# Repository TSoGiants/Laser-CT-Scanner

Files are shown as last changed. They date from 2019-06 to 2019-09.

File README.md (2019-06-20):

# About The Shoulders of Giants
In 1676, Isaac Newton, one of the most influential mathematicians and scientists of all time, famously wrote:

> "If I have seen further, it is by standing on the shoulders of giants."

The Shoulders of Giants, Inc. (TSoG) is a nonprofit (501(c)(3)) organization founded in 2013 on a vision that world-class science education should be available to all students of all ages. Since 2015, The Shoulders of Giants has offered an immersive, ongoing mentorship program for dedicated students who would like the opportunity to study more closely under the guidance of Dr. Steven J. Foland. This program is designed to provide middle and high school students with a broad foundation of knowledge and skills across science and engineering disciplines, experience working and communicating in a professional environment, and helps them develop the study habits necessary to achieve success at the university level and beyond.

In 2019, this world-class program became available to students everywhere with the launch of TSoG.tv. This online platform, created in collaboration between The Shoulders of Giants, Inc. and its sister-company Floating Point Laboratories, LLC, provides at-home exercises, live-streaming, and project support to students anywhere in the world.

## About Work in Progress
Work in Progress (WiP) is the main Kepler-level (high school) series on TSoG.tv, focused on multi-disciplinary engineering and applied science.

As the late, great astrophysicist and science advocate Carl Sagan once said: "If you wish to make an apple pie from scratch, you must first invent the universe." With that great quote in mind, this is a series where we bake the whole pie. In each season of Work in Progress we propose a practical project, lay out specifications, then discuss all of the relevant background knowledge necessary to take that project to completion.

Episodes of WiP air live on www.twitch.tv/tsogtv and are archived at www.youtube.com/tsogtv. This project is based on the work completed in episodes that aired on Monday evenings in Summer 2019.

# Laser CT Scanner
## History and Motivation

## Current State
As the name of the series implies, this redesign is currently a work in progress. This section of the README will be kept up-to-date with the current state of the project as the season progresses.

### Design Inputs
* Should function as closely in general operation to an actual CT scanner as possible.
* At least 1 motorized D.O.F.
* Must be able to independently capture a full 2D slice of an opaque object.
* Must be able to transmit raw data to a computer.
* Must be able to adjust height / z-axis of scan on object (manually or otherwise).

### Stretch Goals
* Able to image semi-opaque materials.
* Scanner rotates around subject rather than rotating the subject.
* Motorized z-axis.

### How to Collaborate
For any active TSoG.tv students who would like to contribute to this project, please create a GitHub account and contact Dr. Foland via Discord. He will need your GitHub username to grant you permission to modify this repository.

This project includes mechanical CAD that we will be completing in Alibre Design. You can download a 30 day trial of this software [here](https://www.alibre.com/get-a-trial-of-alibre-design-expert/). Students active on this project should discuss longer-term licensing options with Dr. Foland.

This project also includes electricad CAD that we will be completing in KiCAD. You can download this open source software [here](http://www.kicad-pcb.org/).

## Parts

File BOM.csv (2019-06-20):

Description | Part Number | Distributor | Link | Unit Cost | Quantity | Total Cost | Notes | Potential Alternative
Line Laser Diode - 5mW 650nm Red | 1057 | Adafruit | https://www.adafruit.com/product/1057 | $8.95 | 1 | $8.95

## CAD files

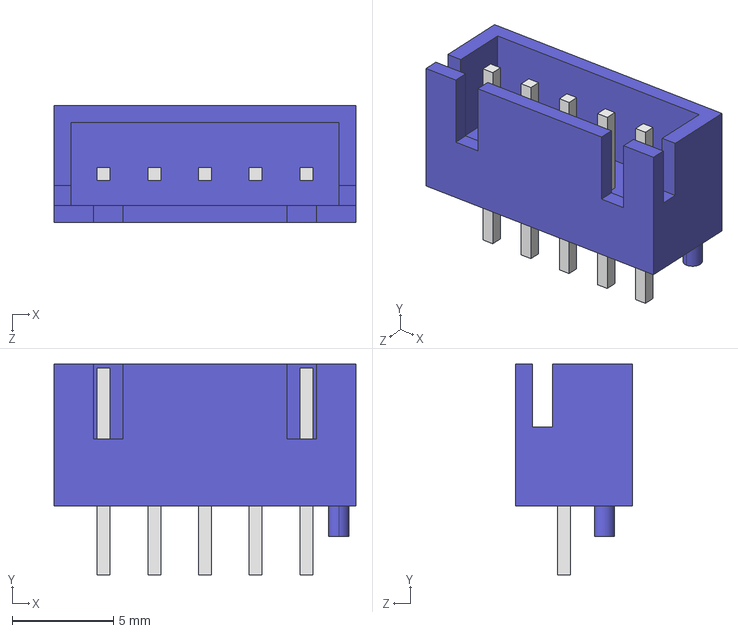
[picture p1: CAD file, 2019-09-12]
Electrical/_lib/3D/B5B-XH-AM.IGS
14.9 x 10.4 x 5.75 mm

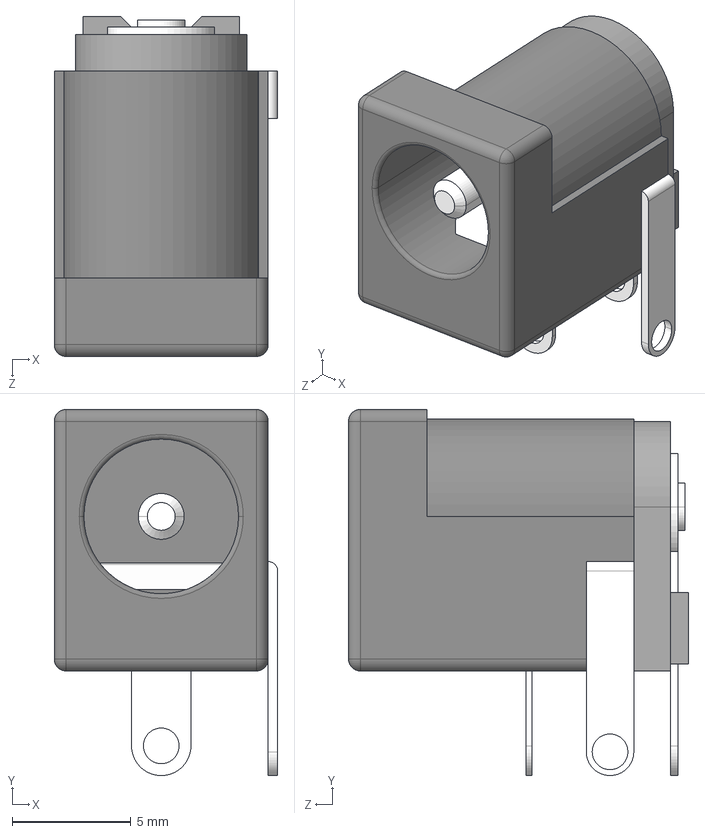
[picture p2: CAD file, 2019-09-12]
Electrical/_lib/3D/DC-005--3DModel-STEP-56544.STEP
9.40 x 15.4 x 14.3 mm

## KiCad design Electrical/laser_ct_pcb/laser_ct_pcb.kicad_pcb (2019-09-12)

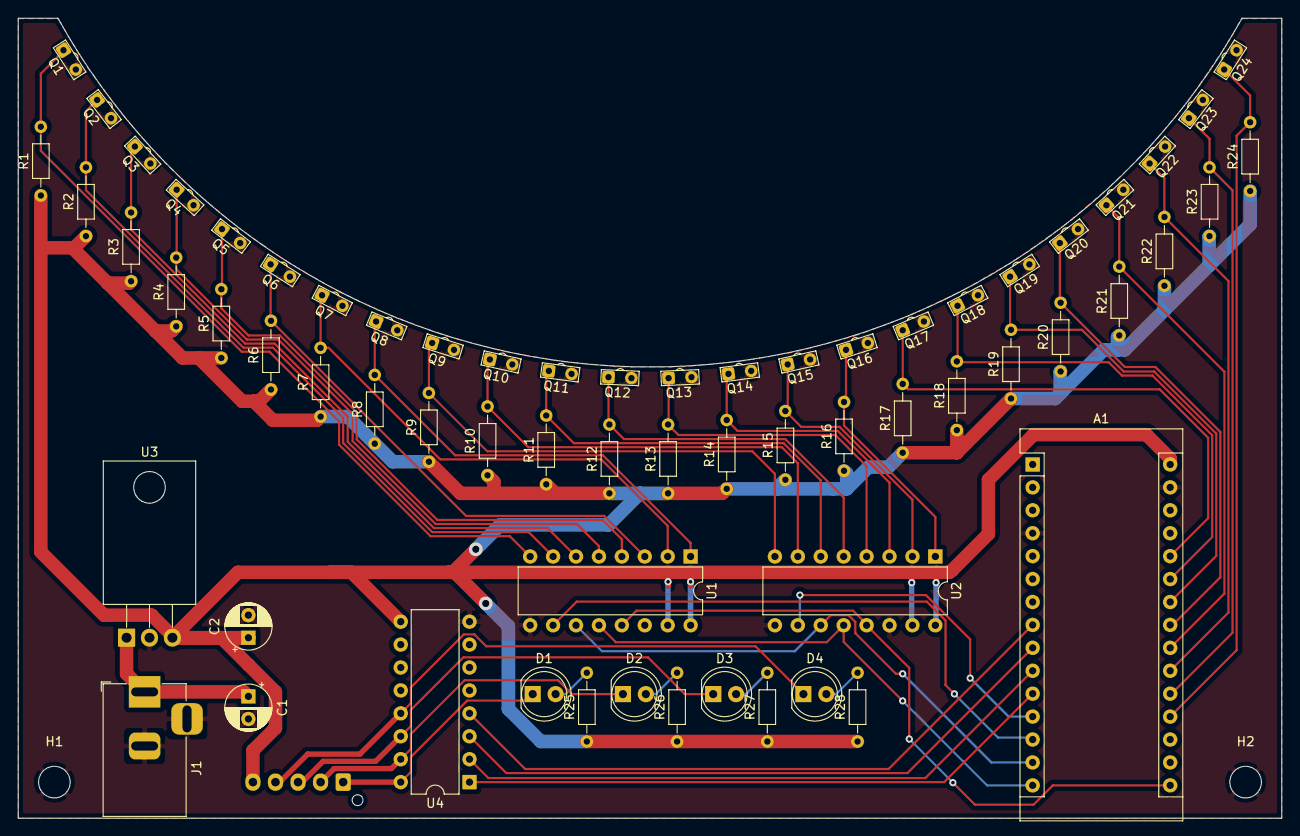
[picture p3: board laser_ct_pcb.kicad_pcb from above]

Board: 2 copper layers, 140.0 x 88.6 mm, 67 parts (1 on the bottom side), 44 nets.

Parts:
A1: Arduino_Nano_v3.x; Arduino_Nano
C1: 0.1uF; CP_Radial_D5.0mm_P2.50mm
C2: 10uF; CP_Radial_D5.0mm_P2.50mm
D1, D2, D3, D4: LED; LED_D5.0mm
H1, H2: MountingHole_Pad; MountingHole_3.5mm
J1: Barrel_Jack_Switch; BarrelJack_Horizontal
M1: 28BYJ-48; JST_XH_B5B-XH-AM_1x05_P2.50mm_Vertical
Q1, Q2, Q3, Q4, Q5, Q6, Q7, Q8, Q9, Q10, Q11, Q12, Q13, Q14, Q15, Q16, Q17, Q18, Q19, Q20, Q21, Q22, Q23, Q24: Q_Photo_NPN; LTR_301
R1, R2, R3, R4, R5, R6, R7, R8, R9, R10, R11, R12, R13, R14, R15, R16, R17, R18, R19, R20, R21, R22, R23, R24: 1 kOhm; R_Axial_DIN0204_L3.6mm_D1.6mm_P7.62mm_Horizontal
R25, R26, R27, R28: R_US; R_Axial_DIN0204_L3.6mm_D1.6mm_P7.62mm_Horizontal
U1, U2: MCP3008; DIP-16_W7.62mm
U3: MIC29310-5.0WT; TO-220-3_Horizontal_TabDown
U4: ULN2003A; DIP-16_W7.62mm

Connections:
+5V: A1.30, C2.1, M1.5, R1.1, R2.1, R3.1, R4.1, R5.1, R6.1, R7.1, R8.1, R9.1, R10.1, R11.1, R12.1, R13.1, R14.1, R15.1, R16.1, R17.1, R18.1, R19.1, R20.1, R21.1, R22.1, R23.1, R24.1, R25.1, R26.1, R27.1, R28.1, U1.15, U1.16, U2.15, U2.16, U3.3, U4.9
+VDC: C1.1, J1.1, U3.1
/A: D1.1, M1.1, U4.16
/B: D2.1, M1.2, U4.15
/C: D3.1, M1.3, U4.14
/D: D4.1, M1.4, U4.13
/M1: A1.11, U4.1
/M2: A1.10, U4.2
/M3: A1.9, U4.3
/M4: A1.8, U4.4
/PT2: Q2.1, R2.2, U1.7
/PT3: Q3.1, R3.2, U1.6
/PT4: Q4.1, R4.2, U1.5
/PT5: Q5.1, R5.2, U1.4
/PT6: Q6.1, R6.2, U1.3
/PT7: Q7.1, R7.2, U1.2
/PT8: Q8.1, R8.2, U1.1
/PT10: Q10.1, R10.2, U2.7
/PT11: Q11.1, R11.2, U2.6
/PT12: Q12.1, R12.2, U2.5
/PT13: Q13.1, R13.2, U2.4
/PT14: Q14.1, R14.2, U2.3
/PT15: Q15.1, R15.2, U2.2
/PT16: Q16.1, R16.2, U2.1
/Phototransistors/PT1: Q1.1, R1.2, U1.8
/Phototransistors/PT9: Q9.1, R9.2, U2.8
/Phototransistors/PT17: A1.26, Q17.1, R17.2
/Phototransistors/PT18: A1.25, Q18.1, R18.2
/Phototransistors/PT19: A1.24, Q19.1, R19.2
/Phototransistors/PT20: A1.23, Q20.1, R20.2
/Phototransistors/PT21: A1.22, Q21.1, R21.2
/Phototransistors/PT22: A1.21, Q22.1, R22.2
/Phototransistors/PT23: A1.20, Q23.1, R23.2
/Phototransistors/PT24: A1.19, Q24.1, R24.2
GND: A1.4, A1.29, C1.2, C2.2, H1.1, H2.1, J1.2, J1.3, Q1.2, Q2.2, Q3.2, Q4.2, Q5.2, Q6.2, Q7.2, Q8.2, Q9.2, Q10.2, Q11.2, Q12.2, Q13.2, Q14.2, Q15.2, Q16.2, Q17.2, Q18.2, Q19.2, Q20.2, Q21.2, Q22.2, Q23.2, Q24.2, U1.9, U1.14, U2.9, U2.14, U3.2, U4.8
unnamed: A1.12, U2.10
unnamed: A1.13, U1.10
unnamed: A1.14, U1.11, U2.11
unnamed: A1.15, U1.12, U2.12
unnamed: A1.16, U1.13, U2.13
unnamed: D1.2, R25.2
unnamed: D2.2, R26.2
unnamed: D3.2, R27.2
unnamed: D4.2, R28.2

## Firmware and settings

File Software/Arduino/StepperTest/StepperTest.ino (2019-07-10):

/*
  Blink

  Turns an LED on for one second, then off for one second, repeatedly.

  Most Arduinos have an on-board LED you can control. On the UNO, MEGA and ZERO
  it is attached to digital pin 13, on MKR1000 on pin 6. LED_BUILTIN is set to
  the correct LED pin independent of which board is used.
  If you want to know what pin the on-board LED is connected to on your Arduino
  model, check the Technical Specs of your board at:
  https://www.arduino.cc/en/Main/Products

  modified 8 May 2014
  by Scott Fitzgerald
  modified 2 Sep 2016
  by Arturo Guadalupi
  modified 8 Sep 2016
  by Colby Newman

  This example code is in the public domain.

  http://www.arduino.cc/en/Tutorial/Blink
*/
#define IN1 2
#define IN2 3
#define IN3 4
#define IN4 5

// the setup function runs once when you press reset or power the board
void setup() {
  // initialize digital pin LED_BUILTIN as an output.
  pinMode(LED_BUILTIN, OUTPUT);
  pinMode(IN1, OUTPUT);
  pinMode(IN2, OUTPUT);
  pinMode(IN3, OUTPUT);
  pinMode(IN4, OUTPUT);
}

// the loop function runs over and over again forever
void loop() {
  digitalWrite(IN1, HIGH);   
  digitalWrite(IN2, LOW);   
  digitalWrite(IN3, LOW);  
  digitalWrite(IN4, LOW);   
  delay(10);
  digitalWrite(IN1, LOW);   
  digitalWrite(IN2, HIGH);   
  digitalWrite(IN3, LOW);  
  digitalWrite(IN4, LOW);  
  delay(10); 
  digitalWrite(IN1, LOW);   
  digitalWrite(IN2, LOW);   
  digitalWrite(IN3, HIGH);  
  digitalWrite(IN4, LOW);  
  delay(10); 
  digitalWrite(IN1, LOW);   
  digitalWrite(IN2, LOW);   
  digitalWrite(IN3, LOW);  
  digitalWrite(IN4, HIGH);  
  delay(10);                       
}

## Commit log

2019-08-08 End of episode 06.
    [laser_ct_pcb.kicad_pcb, laser_ct_pcb.sch]
2019-08-15 End of E07.
    [Phototransistors.sch, laser_ct_pcb.sch, phototransistors.kicad_pcb]
2019-08-22 End of Episode 08.
    [Phototransistors.sch, laser_ct_pcb.kicad_pcb, laser_ct_pcb.sch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]
2019-08-22 Fixed through hole size on ICSP board.
    [Phototransistors.sch, laser_ct_pcb.sch]
2019-08-29 End of episode 09.
    [Phototransistors.sch, laser_ct_pcb.kicad_pcb, laser_ct_pcb.sch]
2019-09-05 End of episode 10.
    [Phototransistors.sch, laser_ct_pcb.kicad_pcb, laser_ct_pcb.sch]
2019-09-07 Added LED indicators for motor coils.
    [LEDs.sch, Phototransistors.sch, laser_ct_pcb.kicad_pcb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]
2019-09-12 End of episode 11.
    [B5B-XH-AM.IGS, DC-005--3DModel-STEP-56544.STEP, LEDs.sch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]
